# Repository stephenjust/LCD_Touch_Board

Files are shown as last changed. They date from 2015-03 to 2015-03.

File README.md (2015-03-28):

# 5-inch LCD / Multitouch Board
Drive an LCD with a multitouch panel using a
[PIC18F14K50](http://ww1.microchip.com/downloads/en/DeviceDoc/41350E.pdf)
and custom PCB!

*The code and CAD files for this project are incomplete, as the
project is under active development. If you have any questions,
please do not hesitate to contact the author.* This project began
in 2013 and has slowly been developed to where it is today in the
free time of the developer as a means to learn more about hardware
design. As such, it is not recommended that this project be used
as a model for commercial work and that developers exercise a
measured amount of caution when using this project.

The schematic and circuit board for this project was designed with
[Eagle 6.6.0](http://www.cadsoftusa.com/eagle-pcb-design-software/about-eagle/).
The board is small enough to be opened with the free version of
Eagle, and only uses two PCB layers. The circuit board can be
purchased from [OSHPark](http://www.oshpark.com) for about $30 USD
for 3 boards.

Assembling this project for yourself is no small task. The project
consists of a very wide range of components, ranging from ordering
custom circuit boards, ordering parts, soldering all of the surface
mount components to the board, and then programming the
microcontroller and eeprom on the board.

Once everything is assembled and running, you should have a small
[800x480 LCD](http://www.newhavendisplay.com/specs/NHD-5.0-800480TF-ATXI-CTP.pdf) 
available via an HDMI or DVI port, and a 5-point touch surface with
which to interact with it.

This project makes use of a [TPS61165](http://www.ti.com/product/tps61165)
LED backlight driver. This is sufficient to drive the backlight
in the LCD panel, and supports dimming via a 1-wire interface or
through PWM.

Please note that this design does not support HDCP, as it uses a
DVI display chip, the [TFP401A](http://www.ti.com/product/tfp401a).
If youi would like to modify this design to support HDCP, you
could build it around the TFP501 instead.

## Latest Schematic
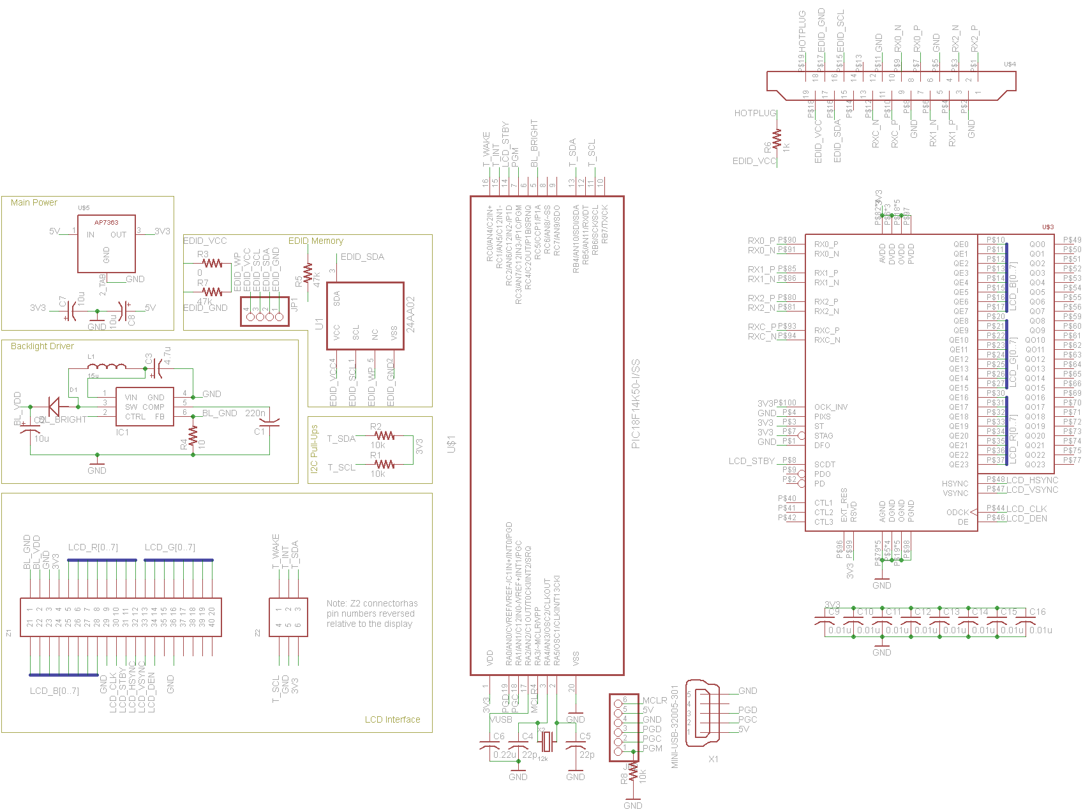
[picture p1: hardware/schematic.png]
Schematic


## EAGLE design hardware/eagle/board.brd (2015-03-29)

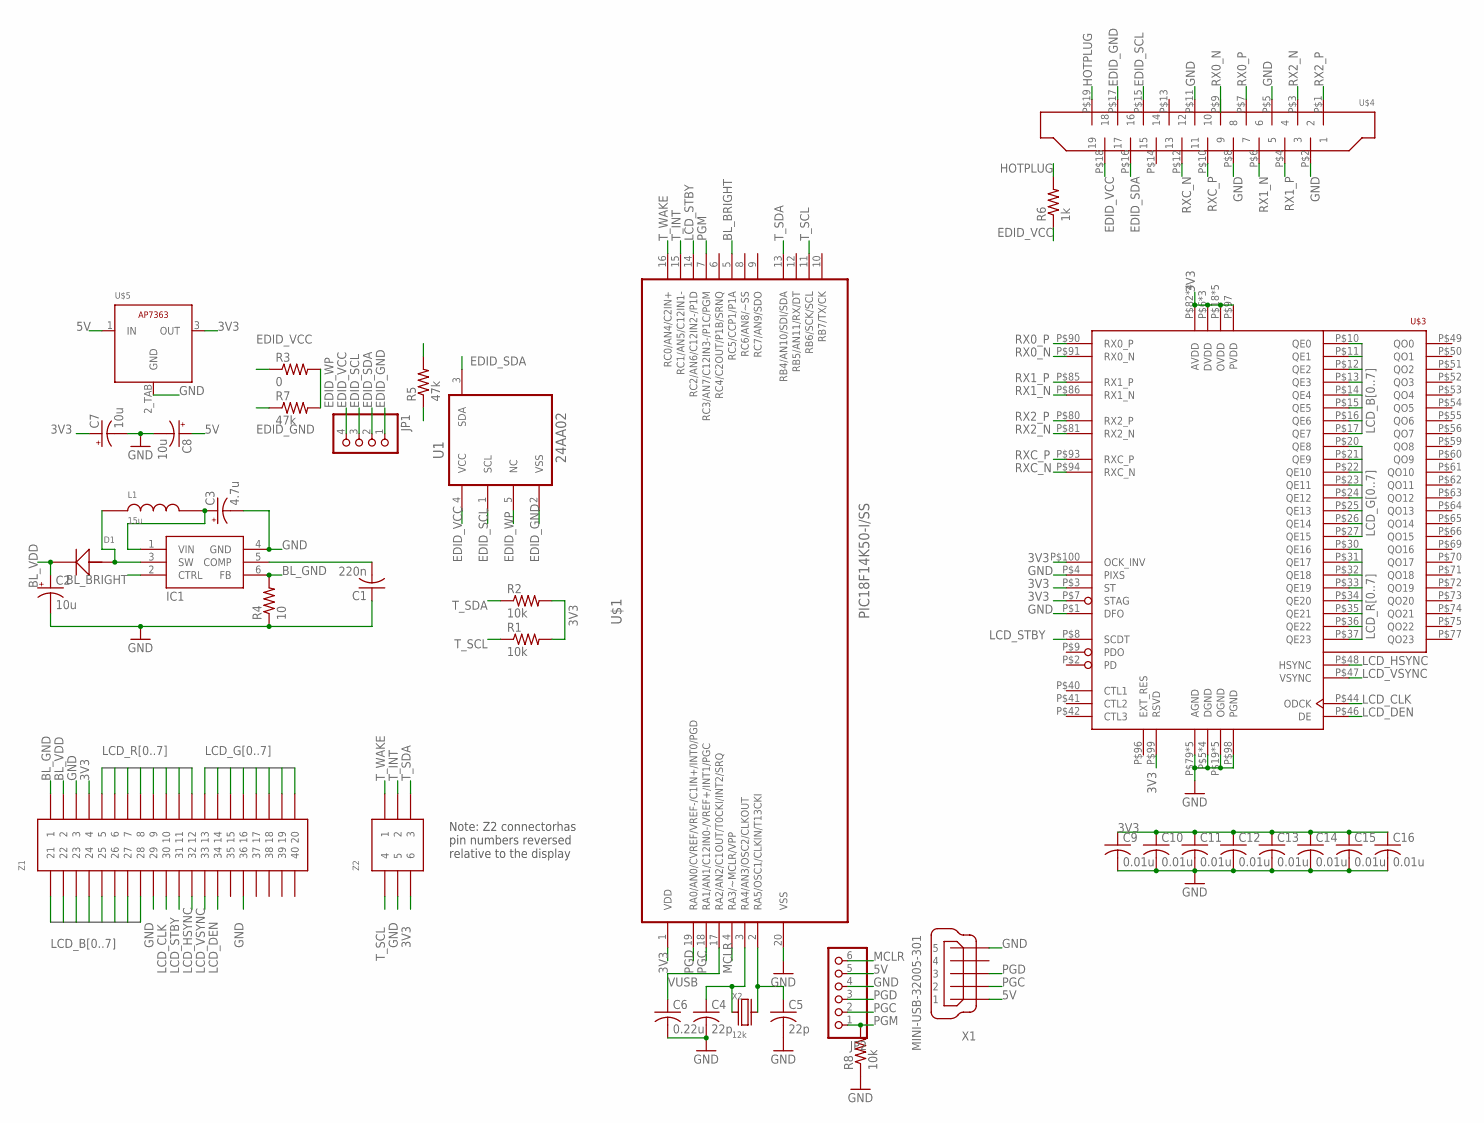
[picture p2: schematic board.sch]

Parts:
C1: 220n; C1206
C2, C7, C8: 10u; PANASONIC_B
C3: 4.7u; PANASONIC_B
C4, C5: 22p; C1206K
C6: 0.22u; C1206K
C9, C10, C11, C12, C13, C14, C15, C16: 0.01u; C0805
D1: MBR0540; SOD123
IC1: TPS61165; SOT-23-6
JP1: PINHD-1X4/90; 1X04/90
JP2: PINHD-1X6; 1X06
L1: 15u; 0520CDMCDS
R1, R2, R8: 10k; R1206
R3: 0; R0805
R4: 10; R0805
R5, R7: 47k; R1206
R6: 1k; R1206
U1: 24AA02; SOT95P270X145-5N
U$1: PIC18F14K50-I/SS; SOP65P780X200-20N
U$3: TFP401; PQFP-100
U$4: HDMI-RCPT; HDMI-RA-SMD
U$5: AP7363TO252; TO252
X1: MINI-USB-32005-301; 32005-301
X2: 12k; CTS-445
Z1: 62684-401100ALF
Z2: 84952-6

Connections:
3V3: C7.+, C9.1, C10.1, C11.1, C12.1, C13.1, C14.1, C15.1, C16.1, R1.2, R2.2, U$1.1 (VDD), U$3.P$3 (ST), U$3.P$6 (DVDD), U$3.P$7 (STAG), U$3.P$18 (OVDD), U$3.P$29 (OVDD), U$3.P$38 (DVDD), U$3.P$43 (OVDD), U$3.P$57 (OVDD), U$3.P$67 (DVDD), U$3.P$78 (OVDD), U$3.P$82 (AVDD), U$3.P$84 (AVDD), U$3.P$88 (AVDD), U$3.P$95 (AVDD), U$3.P$97 (PVDD), U$3.P$99 (RSVD), U$3.P$100 (OCK_INV), U$5.3 (OUT), Z1.4, Z2.6
5V: C3.+, C8.+, IC1.1 (VIN), JP2.5, L1.P$2, U$5.1 (IN), X1.1
BL_BRIGHT: IC1.2 (CTRL), U$1.5 (RC5/CCP1/P1A)
BL_COMP: C1.2, IC1.5 (COMP)
BL_GND: IC1.6 (FB), R4.2, Z1.1
BL_SW: D1.A, IC1.3 (SW), L1.P$1
BL_VDD: C2.+, D1.K, Z1.2
EDID_GND: JP1.1, R7.1, U1.2 (VSS), U$4.P$17 (17)
EDID_SCL: JP1.3, R5.2, U1.1 (SCL), U$4.P$15 (15)
EDID_SDA: JP1.2, U1.3 (SDA), U$4.P$16 (16)
EDID_VCC: JP1.4, R3.1, R5.1, R6.1, U1.4 (VCC), U$4.P$18 (18)
EDID_WP: R3.2, R7.2, U1.5 (NC)
GND: C1.1, C2.-, C3.-, C4.2, C5.2, C6.2, C7.-, C8.-, C9.2, C10.2, C11.2, C12.2, C13.2, C14.2, C15.2, C16.2, IC1.4 (GND), JP2.4, R4.1, R8.1, U$1.20 (VSS), U$3.P$1 (DFO), U$3.P$4 (PIXS), U$3.P$5 (DGND), U$3.P$19 (OGND), U$3.P$28 (OGND), U$3.P$39 (DGND), U$3.P$45 (OGND), U$3.P$58 (OGND), U$3.P$68 (DGND), U$3.P$76 (OGND), U$3.P$79 (AGND), U$3.P$83 (AGND), U$3.P$87 (AGND), U$3.P$89 (AGND), U$3.P$92 (AGND), U$3.P$98 (PGND), U$3.PAD (DGND), U$4.P$2 (2), U$4.P$5 (5), U$4.P$8 (8), U$4.P$11 (11), U$5.2_TAB (GND), X1.5, Z1.3, Z1.29, Z1.36, Z2.5
HOTPLUG: R6.2, U$4.P$19 (19)
LCD_B0: U$3.P$10 (QE0), Z1.21
LCD_B1: U$3.P$11 (QE1), Z1.22
LCD_B2: U$3.P$12 (QE2), Z1.23
LCD_B3: U$3.P$13 (QE3), Z1.24
LCD_B4: U$3.P$14 (QE4), Z1.25
LCD_B5: U$3.P$15 (QE5), Z1.26
LCD_B6: U$3.P$16 (QE6), Z1.27
LCD_B7: U$3.P$17 (QE7), Z1.28
LCD_CLK: U$3.P$44 (ODCK), Z1.30
LCD_DEN: U$3.P$46 (DE), Z1.34
LCD_G0: U$3.P$20 (QE8), Z1.13
LCD_G1: U$3.P$21 (QE9), Z1.14
LCD_G2: U$3.P$22 (QE10), Z1.15
LCD_G3: U$3.P$23 (QE11), Z1.16
LCD_G4: U$3.P$24 (QE12), Z1.17
LCD_G5: U$3.P$25 (QE13), Z1.18
LCD_G6: U$3.P$26 (QE14), Z1.19
LCD_G7: U$3.P$27 (QE15), Z1.20
LCD_HSYNC: U$3.P$48 (HSYNC), Z1.32
LCD_R0: U$3.P$30 (QE16), Z1.5
LCD_R1: U$3.P$31 (QE17), Z1.6
LCD_R2: U$3.P$32 (QE18), Z1.7
LCD_R3: U$3.P$33 (QE19), Z1.8
LCD_R4: U$3.P$34 (QE20), Z1.9
LCD_R5: U$3.P$35 (QE21), Z1.10
LCD_R6: U$3.P$36 (QE22), Z1.11
LCD_R7: U$3.P$37 (QE23), Z1.12
LCD_STBY: U$1.14 (RC2/AN6/C12IN2-/P1D), U$3.P$8 (SCDT), Z1.31
LCD_VSYNC: U$3.P$47 (VSYNC), Z1.33
MCLR: JP2.6, U$1.4 (RA3/~MCLR/VPP)
unnamed: C4.1, U$1.3 (RA4/AN3/OSC2/CLKOUT), X2.X1
unnamed: C5.1, U$1.2 (RA5/OSC1/CLKIN/T13CKI), X2.X2
PGC: JP2.2, U$1.18 (RA1/AN1/C12IN0-/VREF+/INT1/PGC), X1.2
PGD: JP2.3, U$1.19 (RA0/AN0/CVREF/VREF-/C1IN+/INT0/PGD), X1.3
PGM: JP2.1, R8.2, U$1.7 (RC3/AN7/C12IN3-/P1C/PGM)
RX0_N: U$3.P$91 (RX0_N), U$4.P$9 (9)
RX0_P: U$3.P$90 (RX0_P), U$4.P$7 (7)
RX1_N: U$3.P$86 (RX1_N), U$4.P$6 (6)
RX1_P: U$3.P$85 (RX1_P), U$4.P$4 (4)
RX2_N: U$3.P$81 (RX2_N), U$4.P$3 (3)
RX2_P: U$3.P$80 (RX2_P), U$4.P$1 (1)
RXC_N: U$3.P$94 (RXC_N), U$4.P$12 (12)
RXC_P: U$3.P$93 (RXC_P), U$4.P$10 (10)
T_INT: U$1.15 (RC1/AN5/C12IN1-), Z2.2
T_SCL: R1.1, U$1.11 (RB6/SCK/SCL), Z2.4
T_SDA: R2.1, U$1.13 (RB4/AN10/SDI/SDA), Z2.3
T_WAKE: U$1.16 (RC0/AN4/C2IN+), Z2.1
VUSB: C6.1, U$1.17 (RA2/AN2/C1OUT/T0CKI/INT2/SRQ)

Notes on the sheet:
Note: Z2 connectorhas pin numbers reversed relative to the display

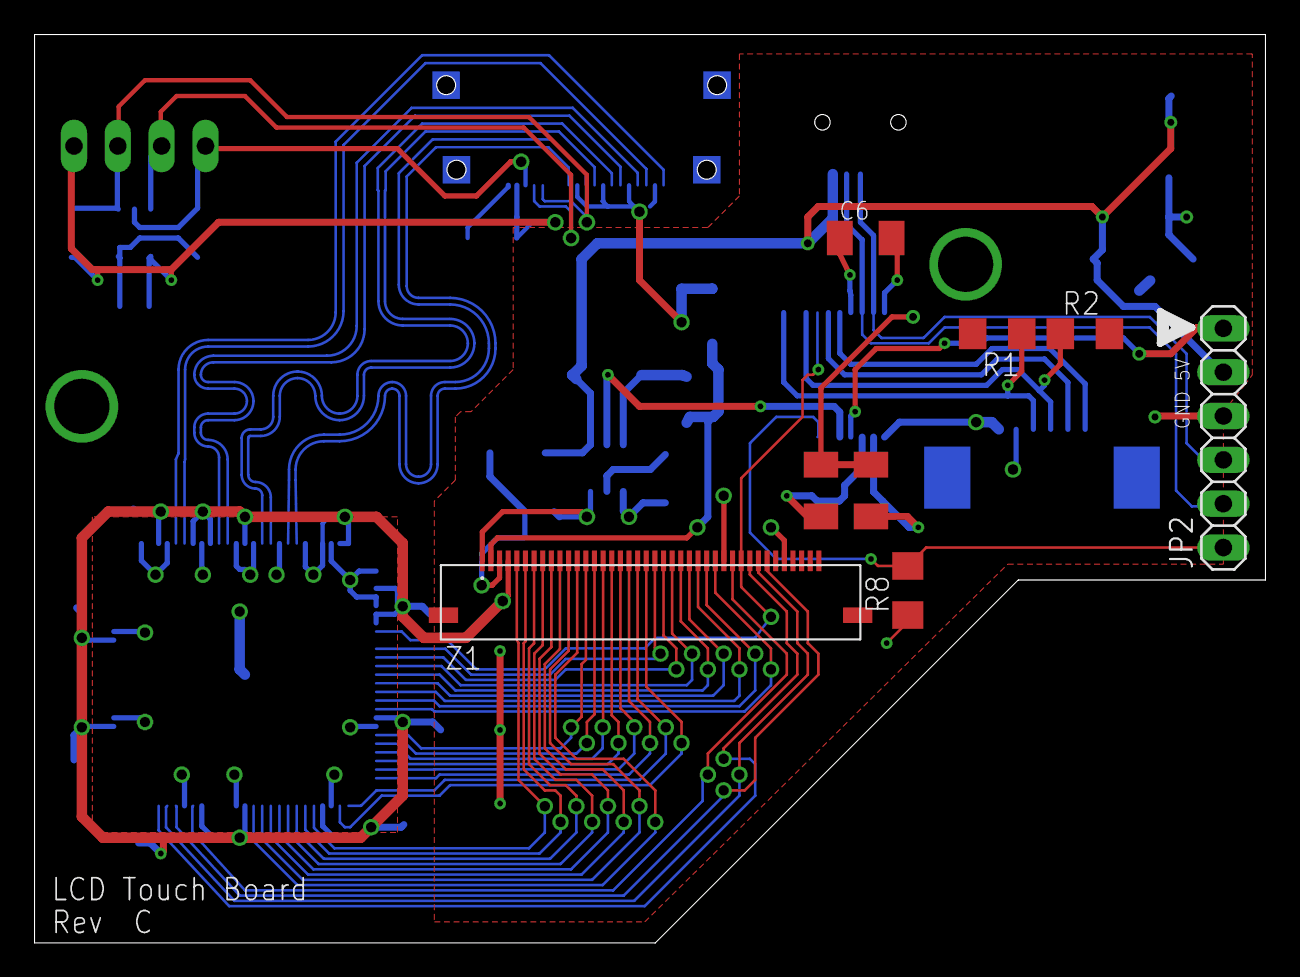
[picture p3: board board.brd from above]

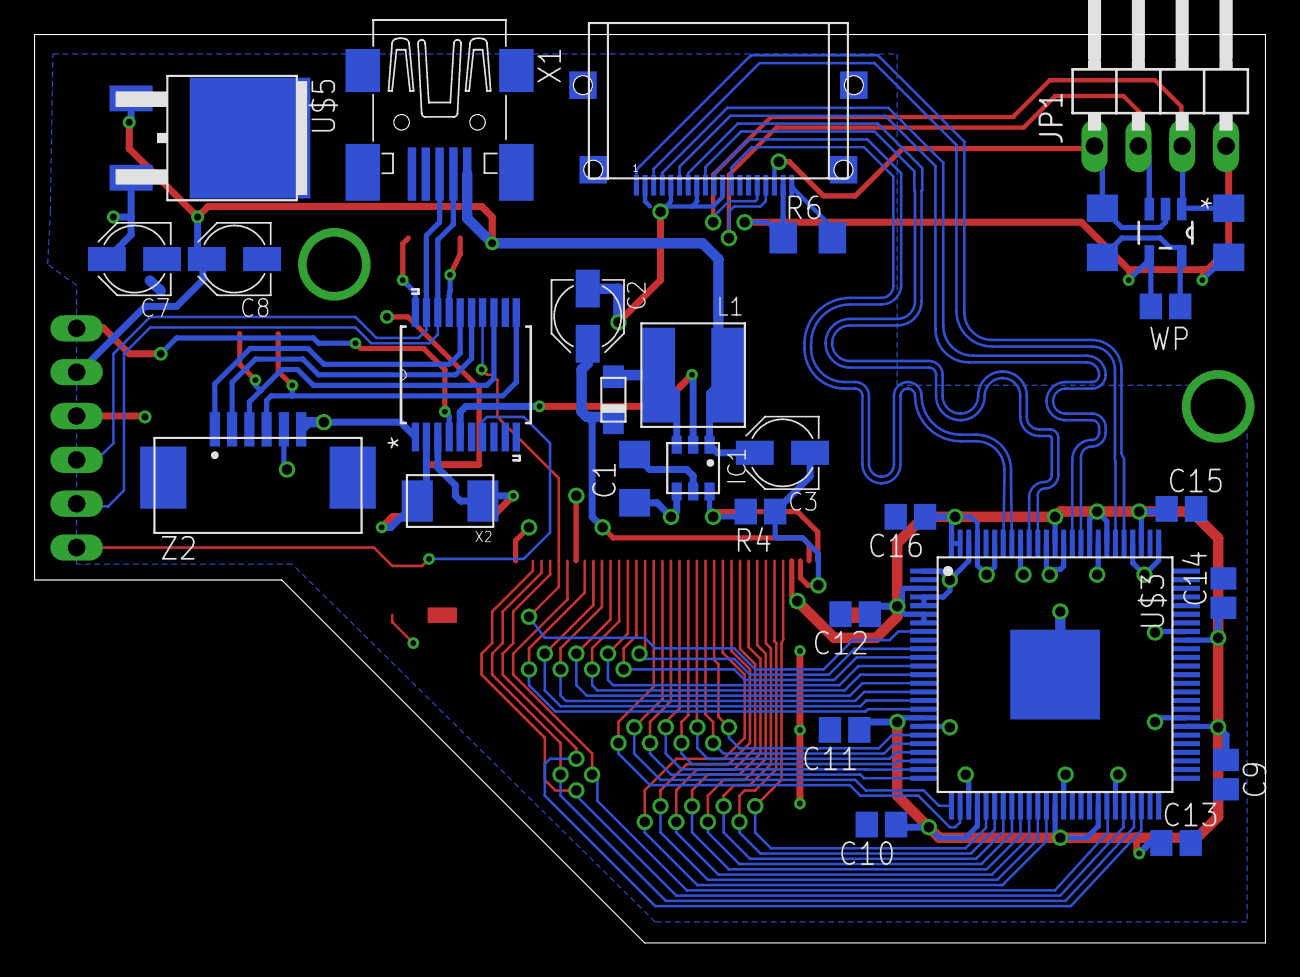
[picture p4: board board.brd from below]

Board: 2 copper layers, 71.3 x 52.6 mm, 38 parts (30 on the bottom side), 62 nets.

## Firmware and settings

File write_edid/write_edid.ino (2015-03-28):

/* This code is from Adafruit's guide for their LCD module
 * https://learn.adafruit.com/adafruit-tfp401-hdmi-slash-dvi-decoder-to-40-pin-ttl-display/editing-the-edid
 */
#include <Wire.h> //I2C library

/* 800x480 ! */ 
const uint8_t PROGMEM eepromdat[128] = {
0x00, 0xFF, 0xFF, 0xFF, 0xFF, 0xFF, 0xFF, 0x00, 0x04, 0x81, 0x04, 0x00, 0x01, 0x00, 0x00, 0x00,
0x01, 0x11, 0x01, 0x03, 0x80, 0x0F, 0x0A, 0x00, 0x0A, 0x00, 0x00, 0x00, 0x00, 0x00, 0x00, 0x00,
0x00, 0x00, 0x00, 0x00, 0x00, 0x00, 0x01, 0x01, 0x01, 0x01, 0x01, 0x01, 0x01, 0x01, 0x01, 0x01,
0x01, 0x01, 0x01, 0x01, 0x01, 0x01, 0x80, 0x0C, 0x20, 0x80, 0x30, 0xE0, 0x2D, 0x10, 0x28, 0x30,
0xD3, 0x00, 0x6C, 0x44, 0x00, 0x00, 0x00, 0x18, 0x00, 0x00, 0x00, 0x10, 0x00, 0x00, 0x00, 0x00,
0x00, 0x00, 0x00, 0x00, 0x00, 0x00, 0x00, 0x00, 0x00, 0x00, 0x00, 0x00, 0x00, 0x10, 0x00, 0x00,
0x00, 0x00, 0x00, 0x00, 0x00, 0x00, 0x00, 0x00, 0x00, 0x00, 0x00, 0x00, 0x00, 0x00, 0x00, 0x10,
0x00, 0x00, 0x00, 0x00, 0x00, 0x00, 0x00, 0x00, 0x00, 0x00, 0x00, 0x00, 0x00, 0x00, 0x00, 0x17,
};

// I2C eeprom dumper
byte i2c_eeprom_read_byte(uint8_t deviceaddress, uint16_t eeaddress );

#define EEPROMSIZE 256UL  // 0.5 Kb
#define ADDRESS_SIZE 8

byte i2c_eeprom_read_byte(uint8_t deviceaddress, uint16_t eeaddress ) {
    byte rdata = 0xFF;
#if (ADDRESS_SIZE == 16)
    Wire.beginTransmission(deviceaddress);
    Wire.write((eeaddress >> 8)); // MSB
#else
    //deviceaddress |= (eeaddress >> 8);
    Wire.beginTransmission(deviceaddress); // MSB
#endif
    Wire.write(eeaddress); // LSB
    Wire.endTransmission();
    Wire.requestFrom(deviceaddress, (uint8_t)1);
    while (!Wire.available()); 
    rdata = Wire.read();
    return rdata;
}

void i2c_eeprom_write_byte(uint8_t deviceaddress, uint16_t eeaddress, byte data ) {
#if (ADDRESS_SIZE == 16)
    Wire.beginTransmission(deviceaddress);
    Wire.write((eeaddress >> 8)); // MSB
#else
    //deviceaddress |= (eeaddress >> 8);
    Wire.beginTransmission(deviceaddress); // MSB
#endif
    Wire.write((byte)eeaddress); // LSB
    Wire.write((byte)data);
    Wire.endTransmission();
}
  

void setup() {
  Wire.begin(); // initialise the connection
  Serial.begin(9600);
  Serial.println(F("EEPROM WRITER"));
  Serial.print(F("EEPROM data size: "));
  Serial.println(sizeof(eepromdat));
  Serial.println(F("Hit any key & return to start"));
  while (!Serial.available());
  byte b;
  Serial.println("Starting");
  for (uint16_t addr = 0; addr < EEPROMSIZE; addr++) {
    if (addr < sizeof(eepromdat)) {
      b = pgm_read_byte(eepromdat+addr);
    } else {
      b = 0xFF;
    }
     i2c_eeprom_write_byte(0x50, addr, b);
     delay(5);
     if ((addr % 32) == 0)
       Serial.println();
     Serial.print("0x");
     if (b < 0x10) Serial.print('0');
     Serial.print(b, HEX); //print content to serial port
     Serial.print(", ");
  }
  Serial.println("\n\r========\n\rFinished!");
  for (uint16_t addr = 0; addr < EEPROMSIZE; addr++) {
    if (addr < sizeof(eepromdat)) {
      b = pgm_read_byte(eepromdat+addr);
    } else {
      b = 0xFF;
    }
    uint8_t d =  i2c_eeprom_read_byte(0x50, addr);
    if ((addr % 32) == 0)
      Serial.println();
    Serial.print("0x");
    if (d < 0x10) Serial.print('0');
    Serial.print(d, HEX); //print content to serial port
    Serial.print(", ");

    if (b != d) {
       Serial.print(F("verification failed at 0x")); Serial.println(addr);
       while (1);
     }
  }
  Serial.println(F("\n\r\n\rVerified!"));
}

void loop() {
}

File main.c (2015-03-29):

/*
 * File:   main.c
 * Author: stephen
 *
 * Created on March 14, 2015, 10:39 PM
 */

#include <xc.h>
#include "backlight.h"
#include "touchpanel.h"
#include "usb/usb.h"
#include "usb/usb_device_hid.h"

#include <app_device_hid_digitizer_multi.h>
#define _XTAL_FREQ 48000000

void interrupt_init(void);

MAIN_RETURN main()
{
    USBDeviceInit();
    USBDeviceAttach();

    bl_init();
    tp_init();

    tp_enable();

    bl_enable();

    while(1)
    {
        /* If the USB device isn't configured yet, we can't really do anything
         * else since we don't have a host to talk to.  So jump back to the
         * top of the while loop. */
        if( USBGetDeviceState() < CONFIGURED_STATE )
        {
            /* Jump back to the top of the while loop. */
            continue;
        }
        /* If we are currently suspended, then we need to see if we need to
         * issue a remote wakeup.  In either case, we shouldn't process any
         * keyboard commands since we aren't currently communicating to the host
         * thus just continue back to the start of the while loop. */
        if( USBIsDeviceSuspended()== true )
        {
            /* Jump back to the top of the while loop. */
            continue;
        }
        //Application specific tasks
        APP_DeviceHIDDigitizerTasks();
    }//end while

}

bool USER_USB_CALLBACK_EVENT_HANDLER(USB_EVENT event, void *pdata, uint16_t size)
{
    switch( (int) event )
    {
        case EVENT_TRANSFER:
            break;

        case EVENT_SOF:
            APP_DeviceHIDDigitizerSOFHandler();
            break;

        case EVENT_SUSPEND:
            break;

        case EVENT_RESUME:
            break;

        case EVENT_CONFIGURED:
            /* When the device is configured, we can (re)initialize the
             * demo code. */
            APP_DeviceHIDDigitizerInitialize();
            break;

        case EVENT_SET_DESCRIPTOR:
            break;

        case EVENT_EP0_REQUEST:
            /* We have received a non-standard USB request.  The HID driver
             * needs to check to see if the request was for it. */
            USBCheckHIDRequest();
            break;

        case EVENT_BUS_ERROR:
            break;

        case EVENT_TRANSFER_TERMINATED:
            break;

        default:
            break;
    }
    return true;
}

void interrupt high_priority isr() {
    if (UEIR) {
            TRISCbits.RC4 = 0;
            LATCbits.LATC4 = 1;

    }
    // Check all USB interrupts
    USBDeviceTasks();
}

void interrupt low_priority isr_low() {
    // Check touch panel interrupt
    tp_service();
}

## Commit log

2015-03-16 Add M-Stack USB library with modifications
    HID descriptors have been modified to match the hardware attached.
    The M-Stack library was also modified to compile with the
    PIC18F14K50.
2015-03-16 Add Eagle files for this design.
    This includes the project files, schematic, board, and custom
    part libraries.
    [board.brd, board.sch]
2015-03-16 Add image of the board schematic
2015-03-18 Attempt to enable USB device based on M-stack ex.
    This did not seem to work, but checking it in
    anyways.
2015-03-18 Add I2C files from old project.
2015-03-19 Remove m-stack, use Microchip's USB HID demo
    m-stack wasn't compatible with my device, but
    the existing Microchip demo code was. So far this
    code is at least properly enabling the usb tranceiver.
2015-03-20 Get USB into a state where it will talk to a PC
    Interrupts with the touch panel are conflicting with USB.
    Will investigate that...
2015-03-20 Attempt to fix touch panel interrupts.
    Still not working, not entirely sure why...
    [main.c, touchpanel.c]
2015-03-22 Sending touch data over USB works now!
    Exact touch details are not yet correct, but this is a good start.
    Data is being transferred from the touch panel to a computer.
    [main.c, touchpanel.c]
2015-03-24 Fix USB descriptors
    USB analyzers inform me that the old descriptor was not correct.
    The new version should be better than the old one.
    Also enabled the backlight.
    [main.c, touchpanel.c]
2015-03-25 Fix byte ordering in USB report and touchpad data
    Lots of byte-ordering issues are fixed now. "In Range"
    field had to be added to match Windows digitizer spec.
    Touch seems to work now.
    [touchpanel.c]
2015-03-28 Added code to write EDID for display
    This code is from Adafruit's tutorial for their TFP401-based design.
    See
    https://learn.adafruit.com/adafruit-tfp401-hdmi-slash-dvi-decoder-to-40-pin-ttl-display/editing-the-edid
2015-03-28 Update Eagle files
    Tweaked design to shrink the PCB, remove
    backlight buttons, and removed the diode
    on MCLR for the microcontroller.
    [board.brd, board.sch]
2015-03-29 Added library for cheaper voltage reg
2015-03-29 Shrank circuit again.
    Circuit board is smaller now, and also has the proper
    wiring for low voltage programming. The missing resistor
    was causing unexpected reboots of the device.
    [board.brd, board.sch]
2015-03-29 Updated schematic image
